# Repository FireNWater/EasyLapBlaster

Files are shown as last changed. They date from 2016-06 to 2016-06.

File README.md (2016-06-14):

EasyRaceLapTimer

# EasyRaceLapTimer

EasyRaceLapTimer is a complete open source IR lap time tracker all-in-one solution for FPV racing quads.



What you get with EasyRaceLaptimer:

**Features:**

* host system for tracking the laps
* IR transponders (code & schematic files for building them) with a transmitting range of 2 to 4 meters
* 63 available transponder IDs when using the project transponders
* changing the ID via a push button on the transponder, no additional programming required (started with version 0.3.1 of the transponders)
* update transponders with new code (Arduino hardware needed)
* setup guide for building your Raspberry PI host station
* the host station is also a WiFi access point to change configs etc on the fly
* monitoring mode, you can watch the stats with your mobile phones
* add your own team logo to the monitoring mode
* detailed stats about pilots and races
* sound effects for various events in a race
* TCP/IP and serial connections support for receiving lap times and commands from other time tracking systems
* export race events to PDF
* standard practice/ time trial mode
* competition mode for racing events with time penalties (satellites needed)
* automatic restarting of a race session after a specified idle time
* and much more comming soon

**Important notices**

EasyRaceLapTimer works basicly with any IR transponder, as long as you provide code for interpreting the IR pulses. Just have a look at the *ir_daemon* tool.

Be sure to use the full size of your SD card on the Raspberry PI

    sudo raspi-config

# Important information

The documentation for the project can be found in the [/docs](https://github.com/polyvision/EasyRaceLapTimer/tree/master/docs) directory.
There's also a huge [RCGroups](http://www.rcgroups.com/forums/showthread.php?t=2538917) thread with lots of answered questions, images etc.

# Version 0.5.x

You can download a SD card image for the PI of EasyRaceLapTimer on the following pages:

http://www.airbirds.de
http://www.easyracelaptimer.com

There's also an introduction video to the system.

# file structure

**/docs**
  documentation of nearly every part of the package

**/web**

the rails application

**/Arduino**

all arduino sketches

**/ir_daemon**

the cpp daemon for receiving the IR pulses

**/datasheets**

schematic files and more for transponders etc.

# Installation

fetch the source via git with the following command

    git clone git@github.com:polyvision/EasyRaceLapTimer.git

more details of each indivial package can be found in the *docs* folder

# Contributors
 * [Peter Provost](https://github.com/PProvost)
 * [Peisel](https://github.com/peisel)
 * [p3root](https://github.com/p3root)
 * [Sven Michel](https://github.com/svenmichel)

# license

The complete project uses the [GPL V3 license](http://www.gnu.org/licenses/gpl-3.0.de.html)

**development and sponsoring by [AirBirds](http://www.airbirds.de)**

Logo Title Text 1

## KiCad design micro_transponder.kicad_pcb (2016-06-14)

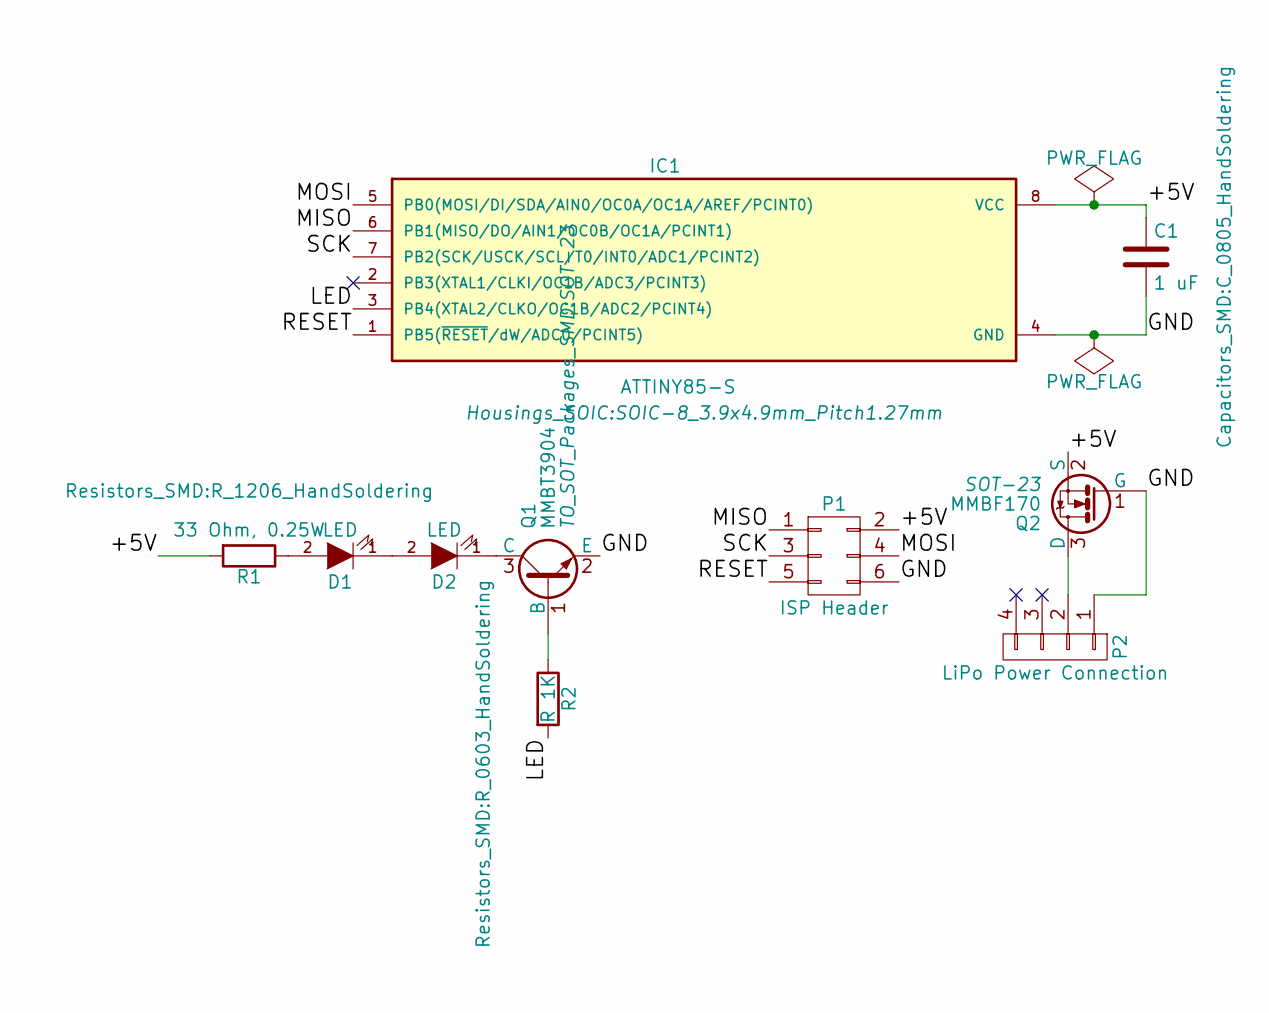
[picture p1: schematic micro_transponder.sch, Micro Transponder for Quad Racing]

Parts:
C1: 1 uF; C_0805_HandSoldering
D1, D2: LED; LED-5MM; DigiKey Part 1497-1205-1-ND
IC1: ATTINY85-S; SOIC-8_3.9x4.9mm_Pitch1.27mm
P1: ISP Header; Pin_Header_Straight_2x03
P2: LiPo Power Connection; Pin_Header_Angled_1x04
Q1: MMBT3904; SOT-23
Q2: MMBF170; SOT-23
R1: 33 Ohm, 0.25W; R_1206_HandSoldering; DigiKey Part 541-150SCT-ND
R2: R 1K; R_0603_HandSoldering

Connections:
/+5V: C1.1, IC1.8 (VCC), P1.2, Q2.2 (S), R1.2
/GND: C1.2, IC1.4 (GND), P1.6, P2.1, Q1.2 (E), Q2.1 (G)
/LED: IC1.3 (PB4(XTAL2/CLKO/OC1B/ADC2/PCINT4)), R2.2
/MISO: IC1.6 (PB1(MISO/DO/AIN1/OC0B/OC1A/PCINT1)), P1.1
/MOSI: IC1.5 (PB0(MOSI/DI/SDA/AIN0/OC0A/OC1A/AREF/PCI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), P1.4
/RESET: IC1.1 (PB5(~RESET~/dW/ADC0/PCINT5)), P1.5
/SCK: IC1.7 (PB2(SCK/USCK/SCL/T0/INT0/ADC1/PCINT2)), P1.3
unnamed: D1.1 (K), D2.2 (A)
unnamed: D1.2 (A), R1.1
unnamed: D2.1 (K), Q1.3 (C)
unnamed: P2.2, Q2.3 (D)
unnamed: Q1.1 (B), R2.1

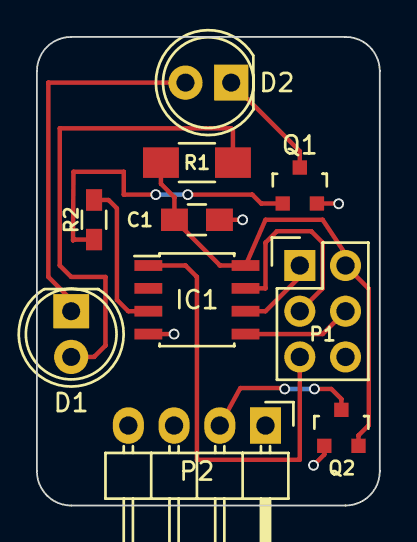
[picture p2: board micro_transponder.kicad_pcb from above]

Board: 2 copper layers, 19.1 x 26.0 mm, 10 parts (0 on the bottom side), 12 nets.
